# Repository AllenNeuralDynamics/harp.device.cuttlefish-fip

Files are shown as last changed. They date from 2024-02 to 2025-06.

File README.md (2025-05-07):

A [Cuttlefish](https://github.com/AllenNeuralDynamics/harp.device.cuttlefish) adapted to a dedicated fiber photometry application.

## Waveform Parameter Overview
This firmware generates the waveform below.

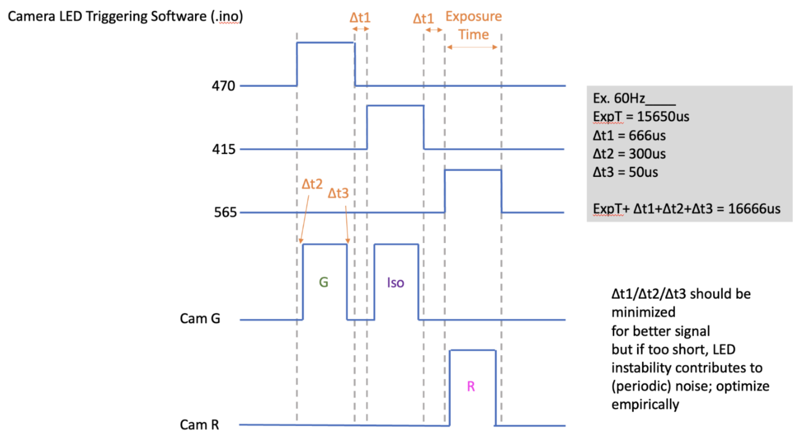
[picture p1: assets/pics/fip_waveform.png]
fip_waveform


Multiple parameters are configurable:
* Continuous, or iterations
* software-trigger to start waveform generation
* `EVENT` message emitted upon rising edge of any camera trigger (configurable)

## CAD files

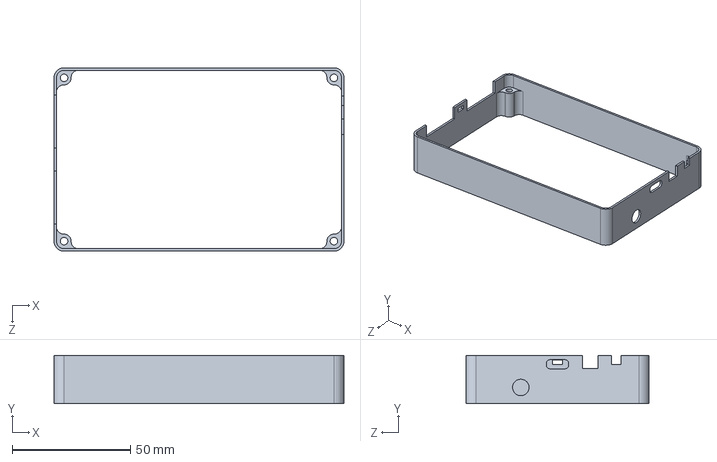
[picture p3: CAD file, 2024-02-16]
hardware/enclosure/cads/solidworks/cuttlefish_enclosure.SLDPRT
122.5 x 20.4 x 77.5 mm

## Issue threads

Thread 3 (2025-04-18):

Device should stop generating waveforms after disconnecting

bruno-f-cruz, 2025-04-18:
If in USB mode, once a client disconnects, would be great to automatically disable all ongoing pulses.

Poofjunior, 2025-04-21:
Ok, this is now implemented in the feat/fip-draft branch.

Upon entering STANDBY (op) mode, the device will disable waveform output, and it's enabled state in the Harp registers will be updated accordingly.

I added a PR to the Harp Core to [make op mode easier to access](https://github.com/harp-tech/core.pico/pull/49).

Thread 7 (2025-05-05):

Allow ongoing tasks to be cancelled immediately

bruno-f-cruz, 2025-05-05:
Currently, the `Stop` command via the reg:

https://github.com/AllenNeuralDynamics/harp.device.cuttlefish-fip/blob/14603b114729877e85d4ecf958180f8078132ae1/device.yml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

awaits for the completion of an ongoing task to take effect. This leads an inability to:

`Stop Task -> Clear Tasks -> Add Task (s) -> Start Tasks` until the first Stop Task is completed. On top of that, since Stop Task does not return an event when it successfully completes, the only thing left to do is to read all tasks, sum all Ts, and await, maximally, that amount of time. This is especially bad if the tasks running have a long duration (e.g., during bleaching or calibration routines).

It would be great if, on top of the current Stop functionality, we could have a value that aborts the currently ongoing sequence instead, regardless of its state.

I propose refactoring the "StartTasks" register into something more like "SetTasksState" that implements an enum:

```
Start 0x01
Stop 0x00
Abort 0x02
(other potential modes in the future like "Pause" and "Resume")
```

Closed 2025-06-28.

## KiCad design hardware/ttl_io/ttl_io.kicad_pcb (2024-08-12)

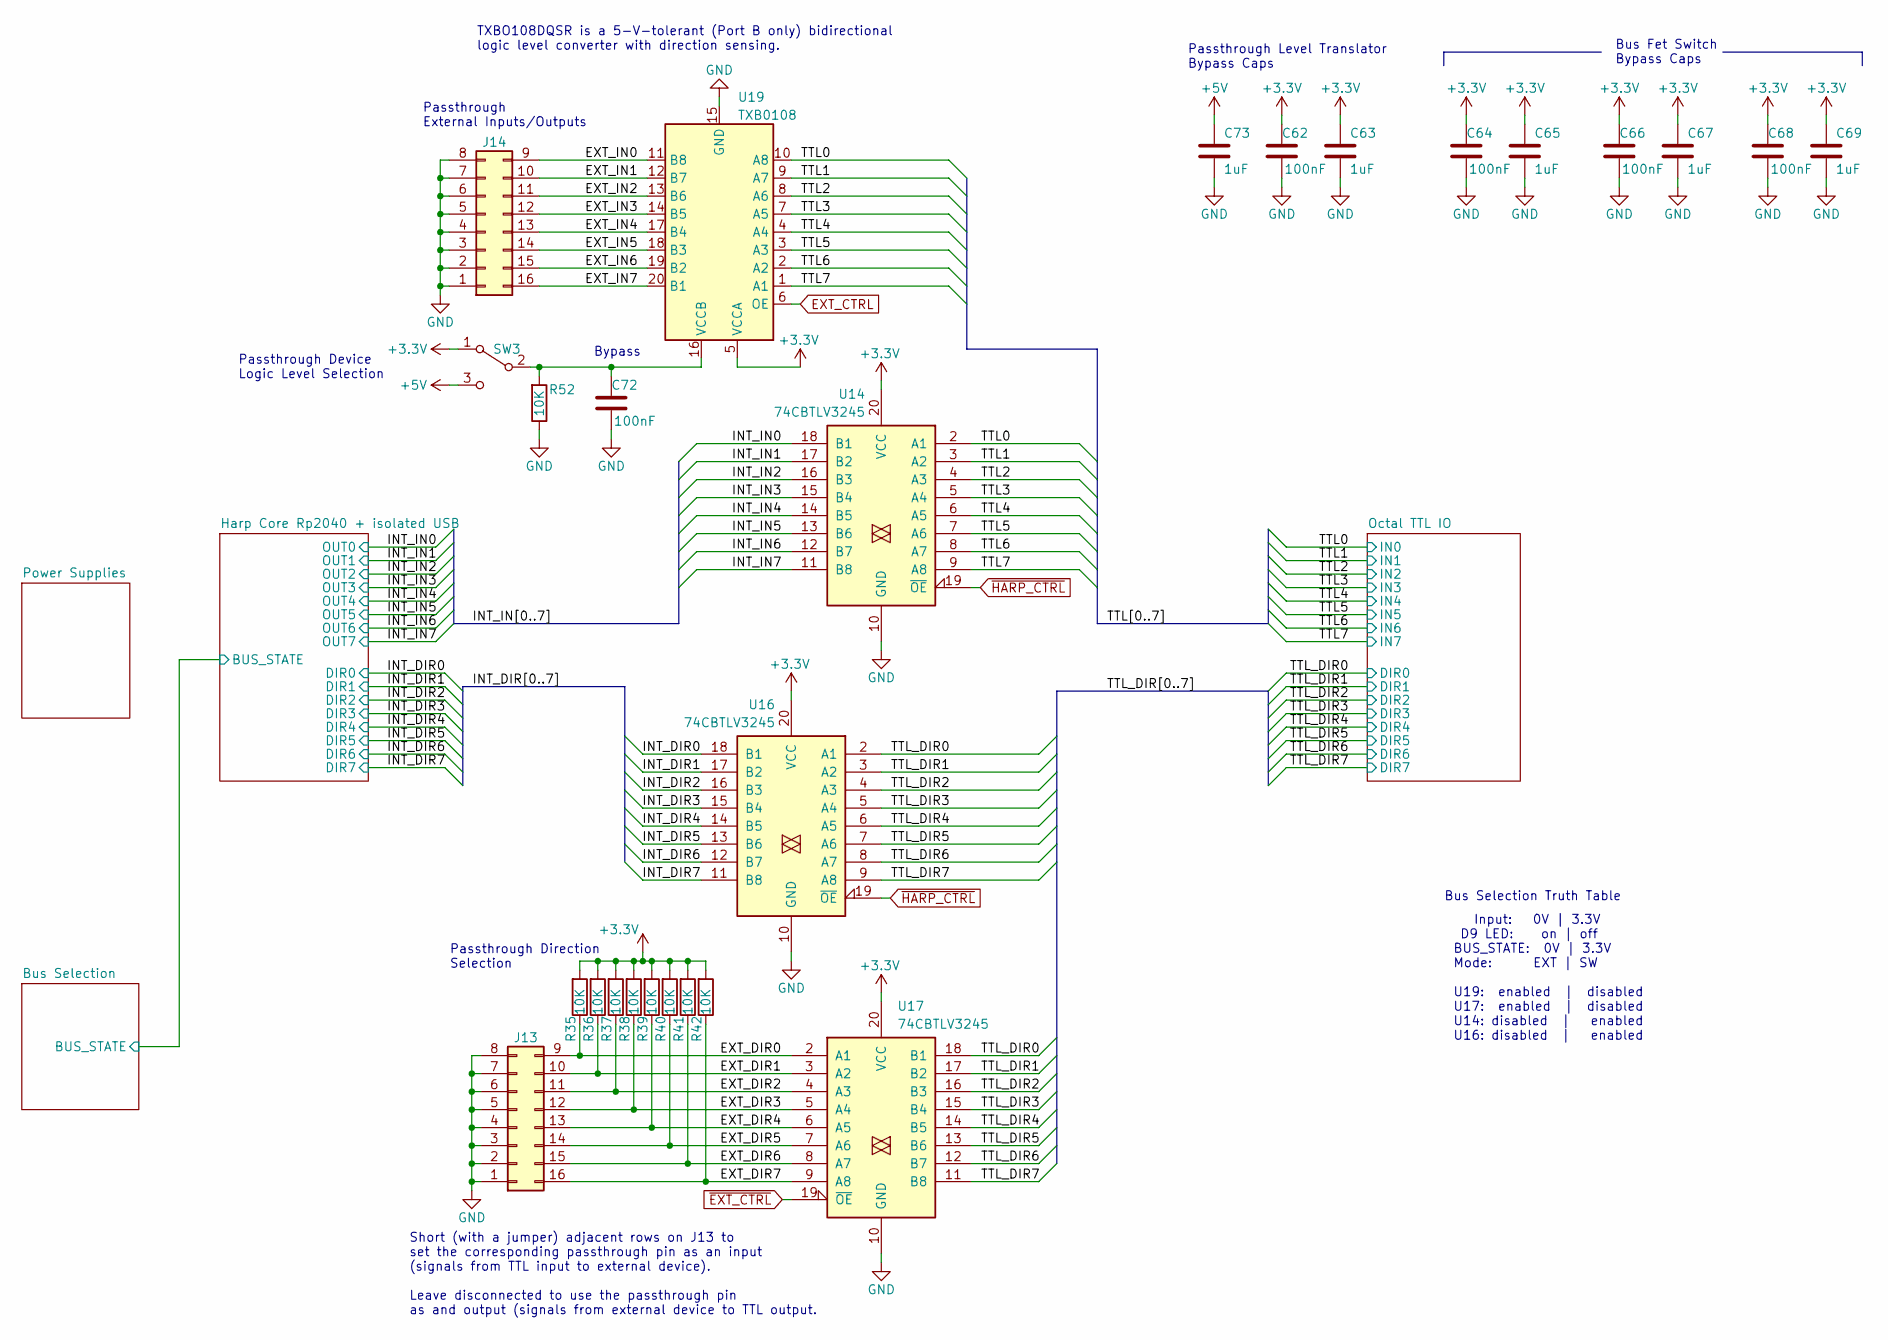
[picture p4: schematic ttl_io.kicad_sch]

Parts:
C62, C64, C66, C68, C72: 100nF; C_0402_1005Metric; Rated Voltage 16V; Tolerance 10%
C63, C65, C67, C69, C73: 1uF; C_0402_1005Metric; Rated Voltage 35V
J13, J14: Conn_02x08_Counter_Clockwise; PinHeader_2x08_P2.54mm_Horizontal_SMD
R35, R36, R37, R38, R39, R40, R41, R42, R52: 10K; R_0402_1005Metric
SW3: SW_SPDT; SW_SPDT_CK-JS102011SAQN
U14, U16, U17: 74CBTLV3245; TSSOP-20_4.4x6.5mm_P0.65mm
U19: TXB0108; TSSOP-20_4.4x6.5mm_P0.65mm

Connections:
+5V: C73.1, SW3.3 (C); also elsewhere on the board
/EXT_DIR0: J13.9, R35.1, U17.2 (A1)
/EXT_DIR1: J13.10, R36.1, U17.3 (A2)
/EXT_DIR2: J13.11, R37.1, U17.4 (A3)
/EXT_DIR3: J13.12, R38.1, U17.5 (A4)
/EXT_DIR4: J13.13, R39.1, U17.6 (A5)
/EXT_DIR5: J13.14, R40.1, U17.7 (A6)
/EXT_DIR6: J13.15, R41.1, U17.8 (A7)
/EXT_DIR7: J13.16, R42.1, U17.9 (A8)
/EXT_IN0: J14.9, U19.11 (B8)
/EXT_IN1: J14.10, U19.12 (B7)
/EXT_IN2: J14.11, U19.13 (B6)
/EXT_IN3: J14.12, U19.14 (B5)
/EXT_IN4: J14.13, U19.17 (B4)
/EXT_IN5: J14.14, U19.18 (B3)
/EXT_IN6: J14.15, U19.19 (B2)
/EXT_IN7: J14.16, U19.20 (B1)
/INT_DIR0: U16.18 (B1); also elsewhere on the board
/INT_DIR1: U16.17 (B2); also elsewhere on the board
/INT_DIR2: U16.16 (B3); also elsewhere on the board
/INT_DIR3: U16.15 (B4); also elsewhere on the board
/INT_DIR4: U16.14 (B5); also elsewhere on the board
/INT_DIR5: U16.13 (B6); also elsewhere on the board
/INT_DIR6: U16.12 (B7); also elsewhere on the board
/INT_DIR7: U16.11 (B8); also elsewhere on the board
/INT_IN0: U14.18 (B1); also elsewhere on the board
/INT_IN1: U14.17 (B2); also elsewhere on the board
/INT_IN2: U14.16 (B3); also elsewhere on the board
/INT_IN3: U14.15 (B4); also elsewhere on the board
/INT_IN4: U14.14 (B5); also elsewhere on the board
/INT_IN5: U14.13 (B6); also elsewhere on the board
/INT_IN6: U14.12 (B7); also elsewhere on the board
/INT_IN7: U14.11 (B8); also elsewhere on the board
/TTL0: U14.2 (A1), U19.10 (A8); also elsewhere on the board
/TTL1: U14.3 (A2), U19.9 (A7); also elsewhere on the board
/TTL2: U14.4 (A3), U19.8 (A6); also elsewhere on the board
/TTL3: U14.5 (A4), U19.7 (A5); also elsewhere on the board
/TTL4: U14.6 (A5), U19.4 (A4); also elsewhere on the board
/TTL5: U14.7 (A6), U19.3 (A3); also elsewhere on the board
/TTL6: U14.8 (A7), U19.2 (A2); also elsewhere on the board
/TTL7: U14.9 (A8), U19.1 (A1); also elsewhere on the board
/TTL_DIR0: U16.2 (A1), U17.18 (B1); also elsewhere on the board
/TTL_DIR1: U16.3 (A2), U17.17 (B2); also elsewhere on the board
/TTL_DIR2: U16.4 (A3), U17.16 (B3); also elsewhere on the board
/TTL_DIR3: U16.5 (A4), U17.15 (B4); also elsewhere on the board
/TTL_DIR4: U16.6 (A5), U17.14 (B5); also elsewhere on the board
/TTL_DIR5: U16.7 (A6), U17.13 (B6); also elsewhere on the board
/TTL_DIR6: U16.8 (A7), U17.12 (B7); also elsewhere on the board
/TTL_DIR7: U16.9 (A8), U17.11 (B8); also elsewhere on the board
EXT_CTRL: U19.6 (OE); also elsewhere on the board
GND: C62.1, C63.2, C64.1, C65.2, C66.1, C67.2, C68.1, C69.2, C72.1, C73.2, J13.1, J13.2, J13.3, J13.4, J13.5, J13.6, J13.7, J13.8, J14.1, J14.2, J14.3, J14.4, J14.5, J14.6, J14.7, J14.8, R52.1, U14.10 (GND), U16.10 (GND), U17.10 (GND), U19.15 (GND); also elsewhere on the board
unnamed: C72.2, R52.2, SW3.2 (B), U19.16 (VCCB)
~EXT_CTRL: U17.19 (~OE); also elsewhere on the board
~HARP_CTRL: U14.19 (~OE), U16.19 (~OE); also elsewhere on the board

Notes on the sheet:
Passthrough External Inputs/Outputs
Input: 0V | 3.3V D9 LED: on | off BUS_STATE: 0V | 3.3V Mode: EXT | SW U19: enabled | disabled U17: enabled | disabled U14: disabled | enabled U16: disabled | enabled
Passthrough Direction Selection
Bus Fet Switch Bypass Caps
TXBO108DQSR is a 5-V-tolerant (Port B only) bidirectional logic level converter with direction sensing.
Short (with a jumper) adjacent rows on J13 to set the corresponding passthrough pin as an input (signals from TTL input to external device). Leave disconnected to use the passthrough pin as and output (signals from external device to TTL output.
Passthrough Device Logic Level Selection
Bypass
Passthrough Level Translator Bypass Caps
Bus Selection Truth Table

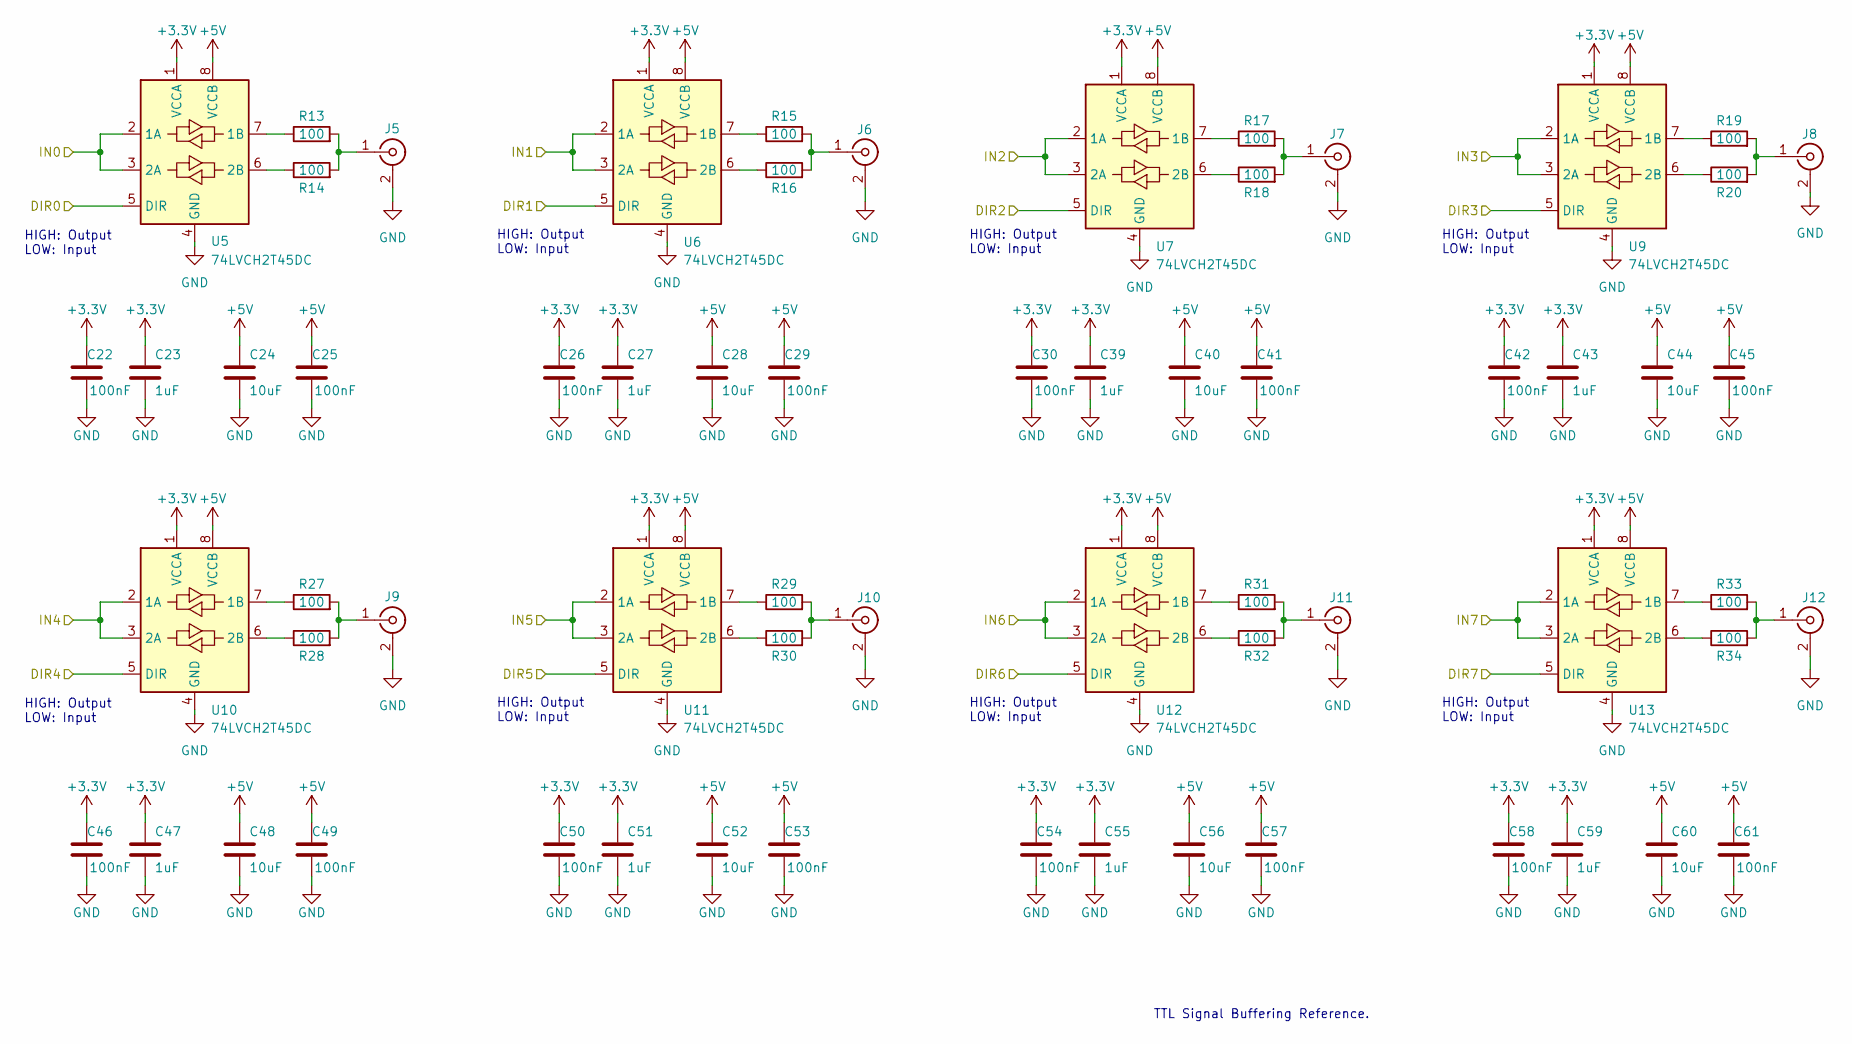
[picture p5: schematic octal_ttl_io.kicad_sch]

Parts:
C22, C25, C26, C29, C30, C41, C42, C45, C46, C49, C50, C53, C54, C57, C58, C61: 100nF; C_0402_1005Metric; Rated Voltage 16V; Tolerance 10%
C23, C27, C39, C43, C47, C51, C55, C59: 1uF; C_0402_1005Metric; Rated Voltage 35V
C24, C28, C40, C44, C48, C52, C56, C60: 10uF; C_0805_2012Metric; Rated Voltage 25V
J5, J6, J7, J8, J9, J10, J11, J12: Conn_Coaxial; BNC_AmphenolRF_031-5329-52RFX_Vertical
R13, R14, R15, R16, R17, R18, R19, R20, R27, R28, R29, R30, R31, R32, R33, R34: 100; R_0402_1005Metric; Tolerance 1%
U5, U6, U7, U9, U10, U11, U12, U13: 74LVCH2T45DC; VSSOP-8_2.3x2mm_P0.5mm

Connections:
+5V: C24.1, C25.2, C28.1, C29.2, C40.1, C41.2, C44.1, C45.2, C48.1, C49.2, C52.1, C53.2, C56.1, C57.2, C60.1, C61.2, U5.8 (VCCB), U6.8 (VCCB), U7.8 (VCCB), U9.8 (VCCB), U10.8 (VCCB), U11.8 (VCCB), U12.8 (VCCB), U13.8 (VCCB); also elsewhere on the board
/TTL0: U5.2 (1A), U5.3 (2A); also elsewhere on the board
/TTL1: U6.2 (1A), U6.3 (2A); also elsewhere on the board
/TTL2: U7.2 (1A), U7.3 (2A); also elsewhere on the board
/TTL3: U9.2 (1A), U9.3 (2A); also elsewhere on the board
/TTL4: U10.2 (1A), U10.3 (2A); also elsewhere on the board
/TTL5: U11.2 (1A), U11.3 (2A); also elsewhere on the board
/TTL6: U12.2 (1A), U12.3 (2A); also elsewhere on the board
/TTL7: U13.2 (1A), U13.3 (2A); also elsewhere on the board
/TTL_DIR0: U5.5 (DIR); also elsewhere on the board
/TTL_DIR1: U6.5 (DIR); also elsewhere on the board
/TTL_DIR2: U7.5 (DIR); also elsewhere on the board
/TTL_DIR3: U9.5 (DIR); also elsewhere on the board
/TTL_DIR4: U10.5 (DIR); also elsewhere on the board
/TTL_DIR5: U11.5 (DIR); also elsewhere on the board
/TTL_DIR6: U12.5 (DIR); also elsewhere on the board
/TTL_DIR7: U13.5 (DIR); also elsewhere on the board
GND: C22.1, C23.2, C24.2, C25.1, C26.1, C27.2, C28.2, C29.1, C30.1, C39.2, C40.2, C41.1, C42.1, C43.2, C44.2, C45.1, C46.1, C47.2, C48.2, C49.1, C50.1, C51.2, C52.2, C53.1, C54.1, C55.2, C56.2, C57.1, C58.1, C59.2, C60.2, C61.1, J5.2 (Ext), J6.2 (Ext), J7.2 (Ext), J8.2 (Ext), J9.2 (Ext), J10.2 (Ext), J11.2 (Ext), J12.2 (Ext), U5.4 (GND), U6.4 (GND), U7.4 (GND), U9.4 (GND), U10.4 (GND), U11.4 (GND), U12.4 (GND), U13.4 (GND); also elsewhere on the board
unnamed: J5.1 (In), R13.2, R14.2
unnamed: J6.1 (In), R15.2, R16.2
unnamed: J7.1 (In), R17.2, R18.2
unnamed: J8.1 (In), R19.2, R20.2
unnamed: J9.1 (In), R27.2, R28.2
unnamed: J10.1 (In), R29.2, R30.2
unnamed: J11.1 (In), R31.2, R32.2
unnamed: J12.1 (In), R33.2, R34.2
unnamed: R13.1, U5.7 (1B)
unnamed: R14.1, U5.6 (2B)
unnamed: R15.1, U6.7 (1B)
unnamed: R16.1, U6.6 (2B)
unnamed: R17.1, U7.7 (1B)
unnamed: R18.1, U7.6 (2B)
unnamed: R19.1, U9.7 (1B)
unnamed: R20.1, U9.6 (2B)
unnamed: R27.1, U10.7 (1B)
unnamed: R28.1, U10.6 (2B)
unnamed: R29.1, U11.7 (1B)
unnamed: R30.1, U11.6 (2B)
unnamed: R31.1, U12.7 (1B)
unnamed: R32.1, U12.6 (2B)
unnamed: R33.1, U13.7 (1B)
unnamed: R34.1, U13.6 (2B)

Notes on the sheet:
HIGH: Output LOW: Input
TTL Signal Buffering Reference.

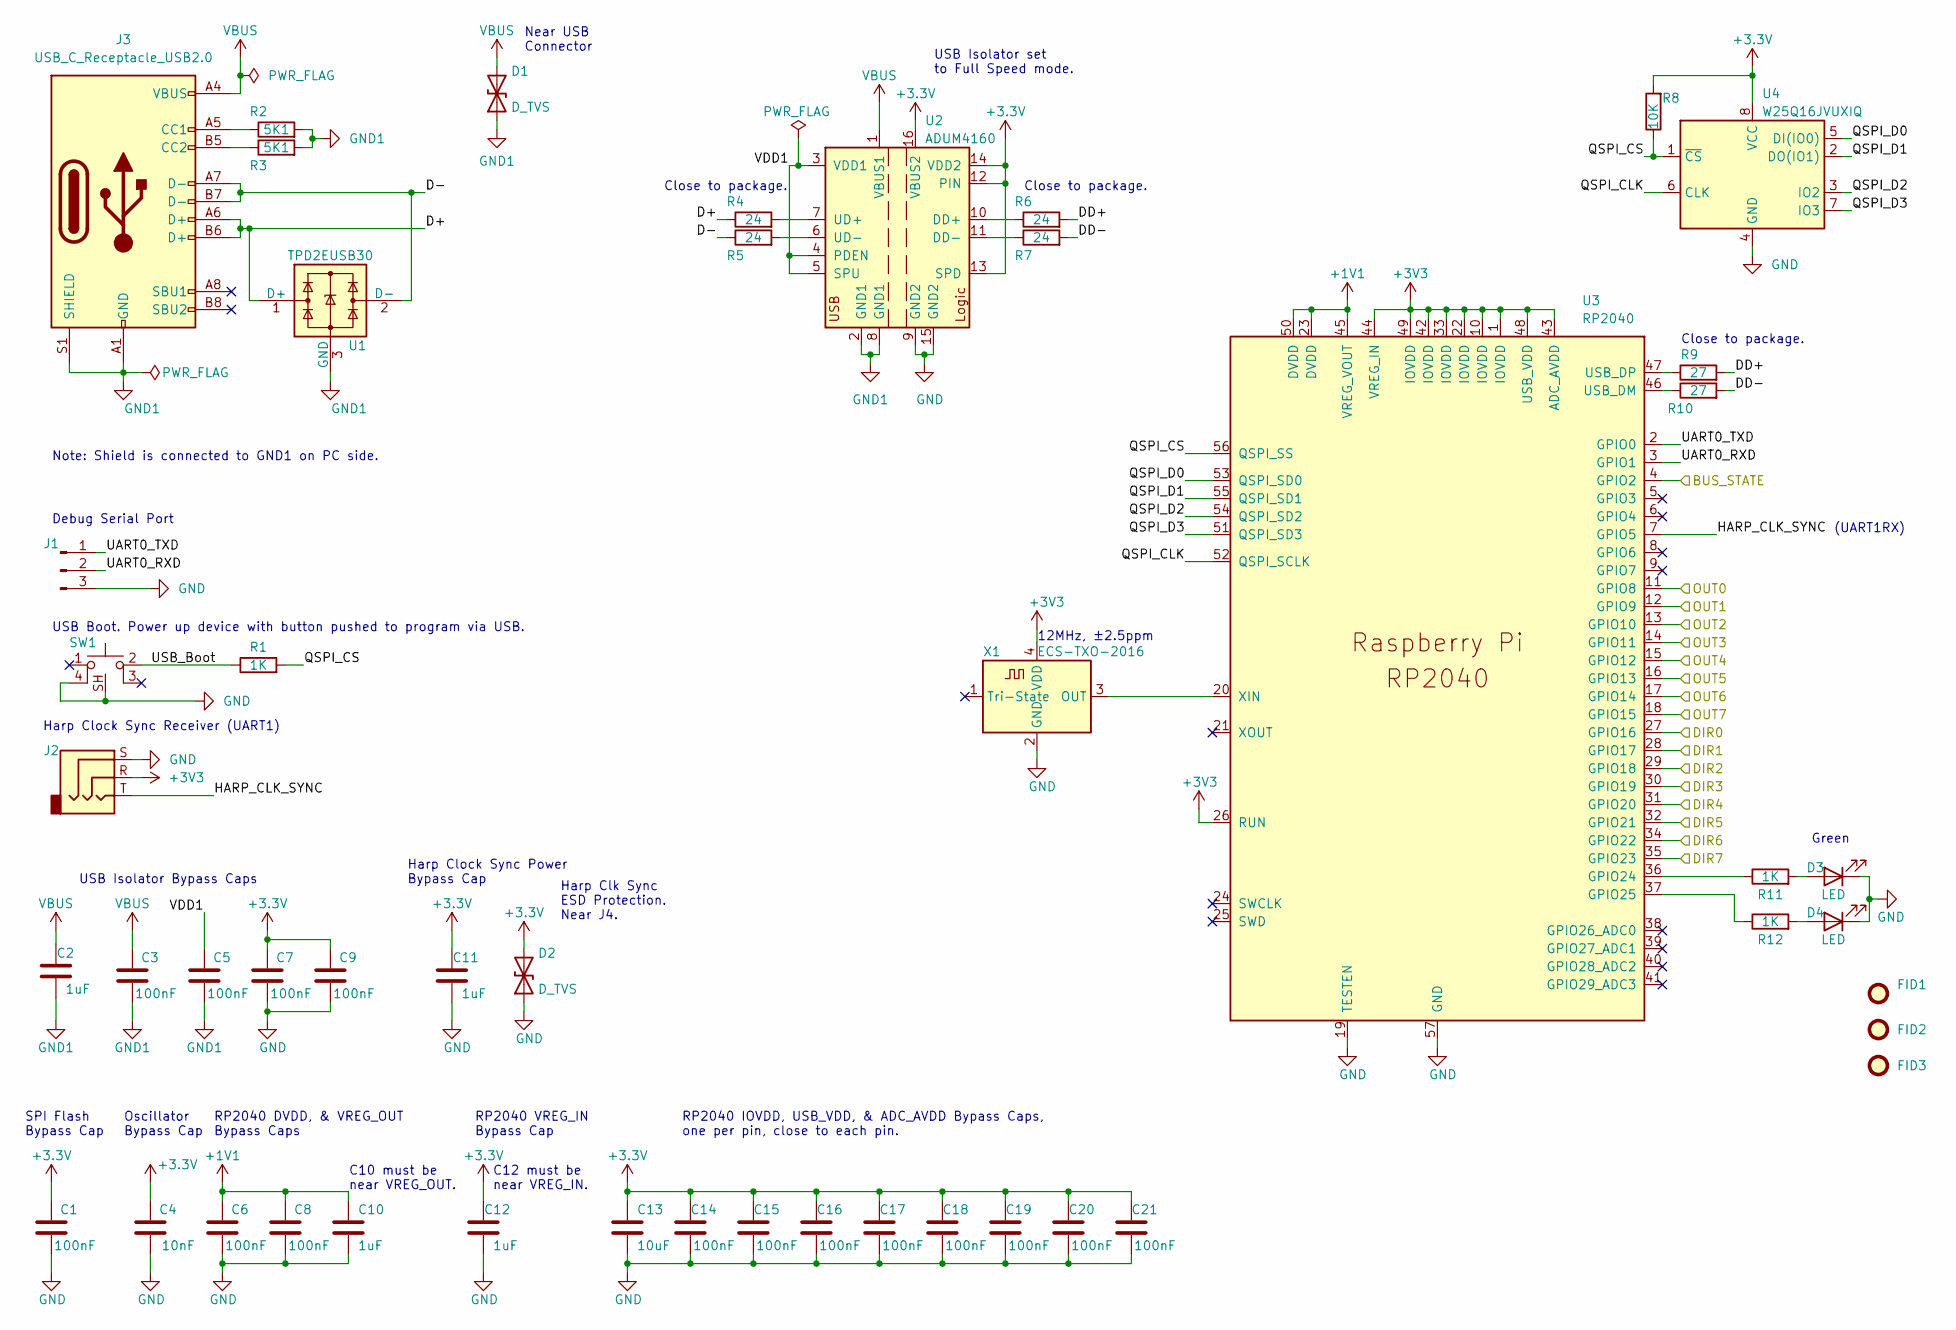
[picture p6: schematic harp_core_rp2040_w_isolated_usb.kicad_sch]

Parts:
C1, C3, C5, C6, C7, C8, C9, C14, C15, C16, C17, C18, C19, C20, C21: 100nF; C_0402_1005Metric; Rated Voltage 16V; Tolerance 10%
C2, C10, C11, C12: 1uF; C_0402_1005Metric; Rated Voltage 35V
C4: 10nF; C_0402_1005Metric; Rated Voltage 25V; Tolerance 10%
C13: 10uF; C_0805_2012Metric; Rated Voltage 25V
D1, D2: D_TVS; D_0402_1005Metric
D3, D4: LED; LED_0603_1608Metric
FID1, FID2, FID3: Fiducial; Fiducial_0.5mm_Mask1mm
J1: Conn_01x03_Male; PinHeader_1x03_P2.54mm_Vertical
J2: AudioJack3; Jack_3.5mm_CUI_SJ-3523-SMT_Horizontal
J3: USB_C_Receptacle_USB2.0; USB_C_Receptacle_JAE_DX07S016JA1R1500
R1, R11, R12: 1K; R_0402_1005Metric; Tolerance 1%
R2, R3: 5K1; R_0402_1005Metric; Tolerance 1%
R4, R5, R6, R7: 24; R_0402_1005Metric; Tolerance 1%
R8: 10K; R_0402_1005Metric
R9, R10: 27; R_0402_1005Metric; Tolerance 1%
SW1: SW_Push_1P1T-SH_NO_Vertical_Wuerth_WS-TASV
U1: TPD2EUSB30; Texas_DRT-3
U2: ADUM4160; SOIC-16W_7.5x10.3mm_P1.27mm
U3: RP2040; RP2040-QFN-56
U4: W25Q16JVUXIQ; Winbond-8USON-2x3mm
X1: ECS-TXO-2016; Crystal_SMD_2016-4Pin_2.0x1.6mm; Tolerance ±2.5ppm

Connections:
+1V1: C6.2, C8.2, C10.1, U3.23 (DVDD), U3.45 (VREG_VOUT), U3.50 (DVDD)
/Bus Selection/BUS_STATE: U3.4 (GPIO2); also elsewhere on the board
/Harp Core Rp2040 + isolated USB/D+: J3.A6 (D+), J3.B6 (D+), R4.1, U1.1 (D+)
/Harp Core Rp2040 + isolated USB/D-: J3.A7 (D-), J3.B7 (D-), R5.1, U1.2 (D-)
/Harp Core Rp2040 + isolated USB/DD+: R6.2, R9.2
/Harp Core Rp2040 + isolated USB/DD-: R7.2, R10.2
/Harp Core Rp2040 + isolated USB/HARP_CLK_SYNC: J2.T, U3.7 (GPIO5)
/Harp Core Rp2040 + isolated USB/QSPI_CLK: U3.52 (QSPI_SCLK), U4.6 (CLK)
/Harp Core Rp2040 + isolated USB/QSPI_CS: R1.2, R8.1, U3.56 (QSPI_SS), U4.1 (~CS)
/Harp Core Rp2040 + isolated USB/QSPI_D0: U3.53 (QSPI_SD0), U4.5 (DI(IO0))
/Harp Core Rp2040 + isolated USB/QSPI_D1: U3.55 (QSPI_SD1), U4.2 (DO(IO1))
/Harp Core Rp2040 + isolated USB/QSPI_D2: U3.54 (QSPI_SD2), U4.3 (IO2)
/Harp Core Rp2040 + isolated USB/QSPI_D3: U3.51 (QSPI_SD3), U4.7 (IO3)
/Harp Core Rp2040 + isolated USB/UART0_RXD: J1.2, U3.3 (GPIO1)
/Harp Core Rp2040 + isolated USB/UART0_TXD: J1.1, U3.2 (GPIO0)
/Harp Core Rp2040 + isolated USB/USB_Boot: R1.1, SW1.2
/Harp Core Rp2040 + isolated USB/VDD1: C5.2, U2.3 (VDD1), U2.4 (PDEN), U2.5 (SPU)
/INT_DIR0: U3.27 (GPIO16); also elsewhere on the board
/INT_DIR1: U3.28 (GPIO17); also elsewhere on the board
/INT_DIR2: U3.29 (GPIO18); also elsewhere on the board
/INT_DIR3: U3.30 (GPIO19); also elsewhere on the board
/INT_DIR4: U3.31 (GPIO20); also elsewhere on the board
/INT_DIR5: U3.32 (GPIO21); also elsewhere on the board
/INT_DIR6: U3.34 (GPIO22); also elsewhere on the board
/INT_DIR7: U3.35 (GPIO23); also elsewhere on the board
/INT_IN0: U3.11 (GPIO8); also elsewhere on the board
/INT_IN1: U3.12 (GPIO9); also elsewhere on the board
/INT_IN2: U3.13 (GPIO10); also elsewhere on the board
/INT_IN3: U3.14 (GPIO11); also elsewhere on the board
/INT_IN4: U3.15 (GPIO12); also elsewhere on the board
/INT_IN5: U3.16 (GPIO13); also elsewhere on the board
/INT_IN6: U3.17 (GPIO14); also elsewhere on the board
/INT_IN7: U3.18 (GPIO15); also elsewhere on the board
GND: C1.1, C4.1, C6.1, C7.1, C8.1, C9.1, C10.2, C11.2, C12.2, C13.2, C14.1, C15.1, C16.1, C17.1, C18.1, C19.1, C20.1, C21.1, D2.1 (A1), D3.1 (K), D4.1 (K), J1.3, J2.S, SW1.4, SW1.SH, U2.9 (GND2), U2.15 (GND2), U3.19 (TESTEN), U3.57 (GND), U4.4 (GND), X1.2 (GND); also elsewhere on the board
GND1: C2.2, C3.1, C5.1, D1.1 (A1), J3.A1 (GND), J3.A12 (GND), J3.B1 (GND), J3.B12 (GND), J3.S1 (SHIELD), R2.2, R3.2, U1.3 (GND), U2.2 (GND1), U2.8 (GND1)
unnamed: D3.2 (A), R11.2
unnamed: D4.2 (A), R12.2
unnamed: J3.A5 (CC1), R2.1
unnamed: J3.B5 (CC2), R3.1
unnamed: R6.1, U2.10 (DD+)
unnamed: R7.1, U2.11 (DD-)
unnamed: R4.2, U2.7 (UD+)
unnamed: R5.2, U2.6 (UD-)
unnamed: R11.1, U3.36 (GPIO24)
unnamed: R12.1, U3.37 (GPIO25)
unnamed: R10.1, U3.46 (USB_DM)
unnamed: R9.1, U3.47 (USB_DP)
unnamed: U3.20 (XIN), X1.3 (OUT)
VBUS: C2.1, C3.2, D1.2 (A2), J3.A4 (VBUS), J3.A9 (VBUS), J3.B4 (VBUS), J3.B9 (VBUS), U2.1 (VBUS1)

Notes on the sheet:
USB Isolator Bypass Caps
Near USB Connector
Close to package.
Harp Clock Sync Power Bypass Cap
USB Isolator set to Full Speed mode.
12MHz, ±2.5ppm
Debug Serial Port
USB Boot. Power up device with button pushed to program via USB.
(UART1RX)
Harp Clock Sync Receiver (UART1)
Note: Shield is connected to GND1 on PC side.
RP2040 DVDD, & VREG_OUT Bypass Caps
RP2040 IOVDD, USB_VDD, & ADC_AVDD Bypass Caps, one per pin, close to each pin.
C10 must be near VREG_OUT.
RP2040 VREG_IN Bypass Cap
SPI Flash Bypass Cap
Harp Clk Sync ESD Protection. Near J4.
Oscillator Bypass Cap
C12 must be near VREG_IN.
Green

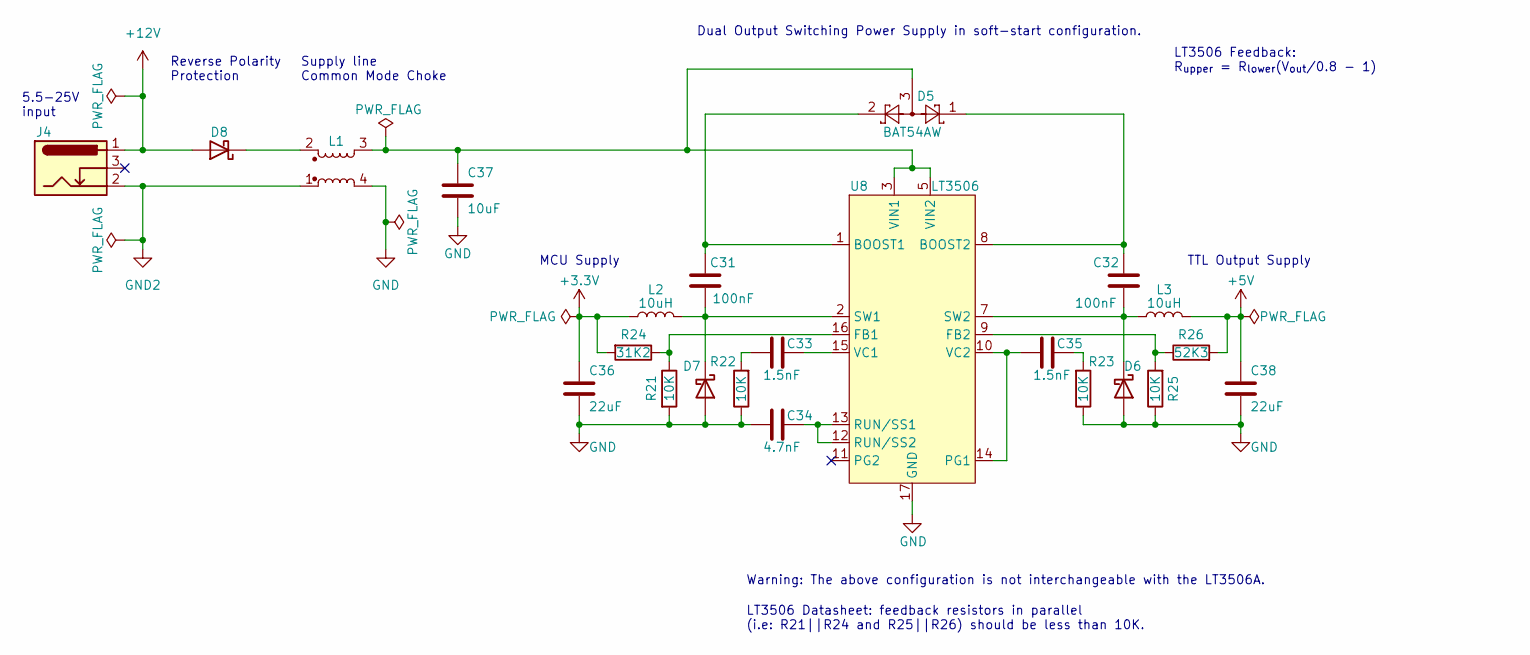
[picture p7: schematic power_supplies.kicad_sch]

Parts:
C31, C32: 100nF; C_0402_1005Metric; Rated Voltage 16V; Tolerance 10%
C33: 1.5nF; R_0402_1005Metric; Tolerance 10%; Voltage Rating 50V
C34: 4.7nF; R_0402_1005Metric; Tolerance 10%; Voltage Rating 50V
C35: 1.5nF; R_0402_1005Metric; Tolerance 10%
C36, C38: 22uF; C_0805_2012Metric; Rated Voltage 25V
C37: 10uF; C_0805_2012Metric; Rated Voltage 25V
D5: BAT54AW; SOT-323_SC-70
D6, D7, D8: D_Schottky; D_SOD-123
J4: Barrel_Jack_Switch; BarrelJack_CUI_PJ-102AH_Horizontal
L1: L_Coupled_1423; L_CommonModeChoke_TDKCorporation_1210
L2, L3: 10uH; L_Vishay_IHLP-2525
R21, R22, R23, R25: 10K; R_0402_1005Metric
R24: 31K2; R_0402_1005Metric; Tolerance 1%
R26: 52K3; R_0402_1005Metric; Tolerance 1%
U8: LT3506; DFN-16-1EP_4x5mm_P0.5mm_EP2.44x4.34mm

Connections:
+5V: C38.1, L3.2, R26.2; also elsewhere on the board
+12V: D8.2 (A), J4.1
GND: C34.1, C36.2, C37.2, C38.2, D6.2 (A), D7.2 (A), L1.4, R21.2, R22.1, R23.1, R25.1, U8.17 (GND); also elsewhere on the board
GND2: J4.2, L1.1
unnamed: C33.1, R22.2
unnamed: C35.2, R23.2
unnamed: C32.1, D6.1 (K), L3.1, U8.7 (SW2)
unnamed: C31.1, D7.1 (K), L2.2, U8.2 (SW1)
unnamed: D8.1 (K), L1.2
unnamed: C31.2, D5.2, U8.1 (BOOST1)
unnamed: C32.2, D5.1, U8.8 (BOOST2)
unnamed: R21.1, R24.1, U8.16 (FB1)
unnamed: R25.2, R26.1, U8.9 (FB2)
unnamed: C35.1, U8.10 (VC2), U8.14 (PG1)
unnamed: C34.2, U8.12 (RUN/SS2), U8.13 (RUN/SS1)
unnamed: C33.2, U8.15 (VC1)
VIN1: C37.1, D5.3, L1.3, U8.3 (VIN1), U8.4 (VIN1), U8.5 (VIN2), U8.6 (VIN2)

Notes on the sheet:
Reverse Polarity Protection
LT3506 Datasheet: feedback resistors in parallel (i.e: R21||R24 and R25||R26) should be less than 10K.
TTL Output Supply
Supply line Common Mode Choke
Dual Output Switching Power Supply in soft-start configuration.
LT3506 Feedback: R_{upper} = R_{lower}(V_{out}/0.8 - 1)
Warning: The above configuration is not interchangeable with the LT3506A.
MCU Supply
5.5-25V input

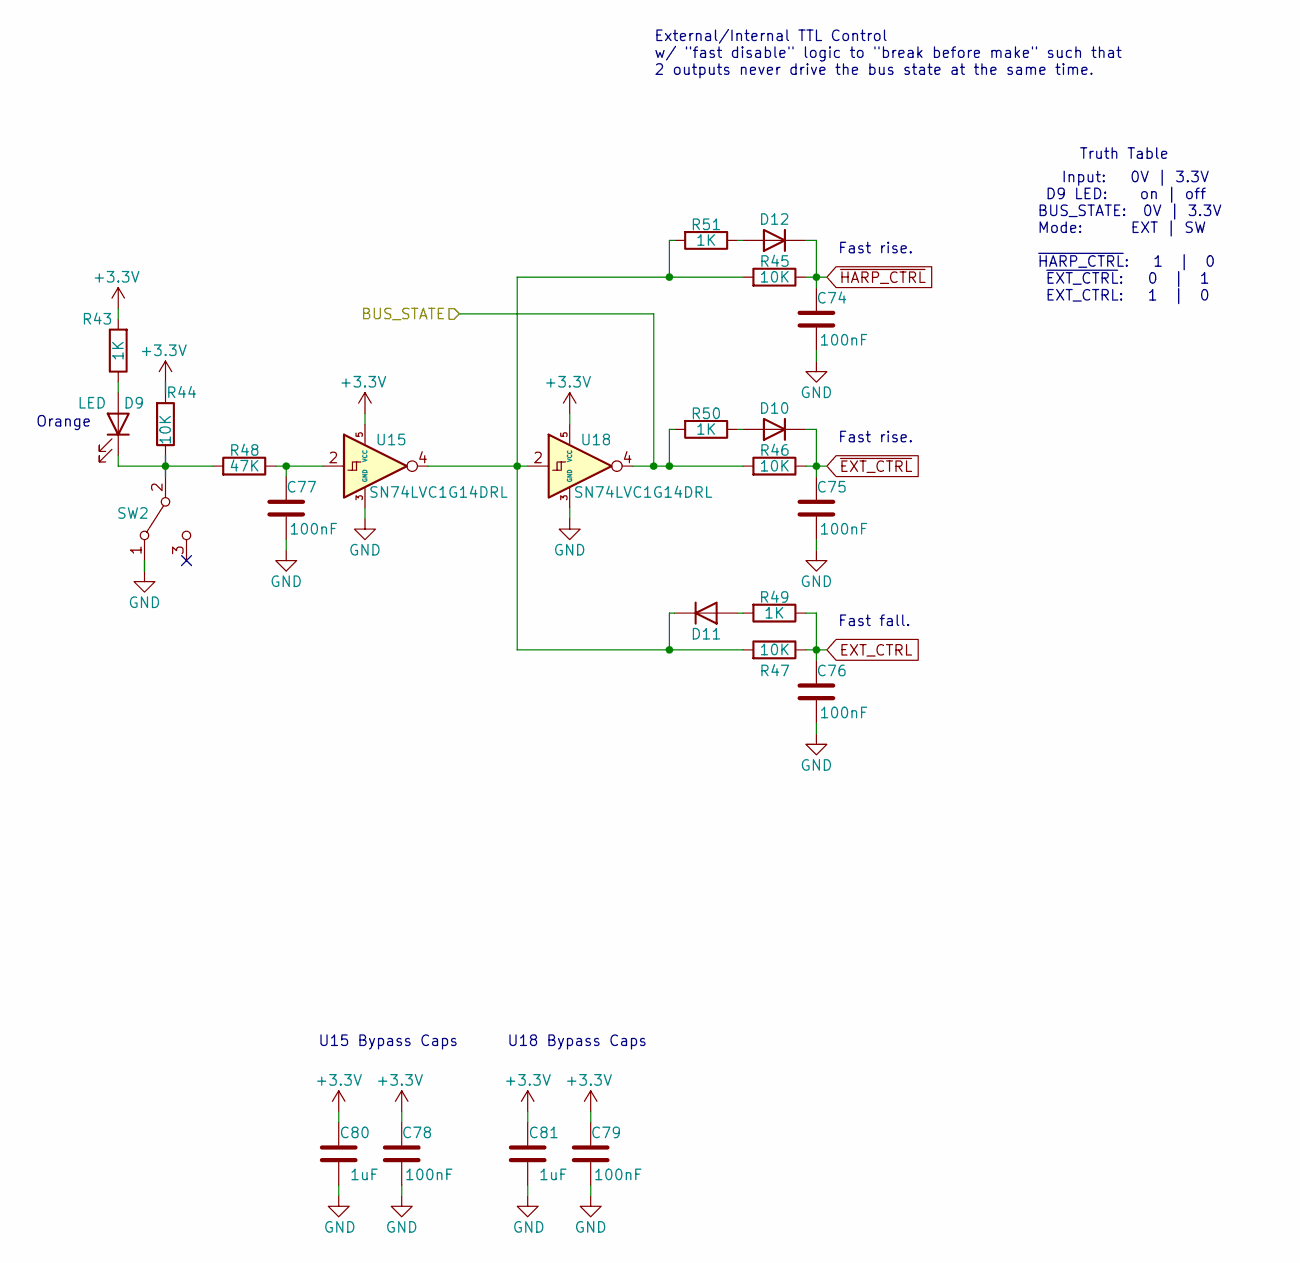
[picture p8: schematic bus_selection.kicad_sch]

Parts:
C74, C75, C76, C77, C78, C79: 100nF; C_0402_1005Metric; Rated Voltage 16V; Tolerance 10%
C80, C81: 1uF; C_0402_1005Metric; Rated Voltage 35V
D9: LED; LED_0603_1608Metric
D10, D11, D12: NSR05F40NXT5G; D_0402_1005Metric
R43, R49, R50, R51: 1K; R_0402_1005Metric; Tolerance 1%
R44, R45, R46, R47: 10K; R_0402_1005Metric
R48: 47K; R_0402_1005Metric; Tolerance 1%
SW2: SW_SPDT; SW_SPDT_CK-JS102011SAQN
U15, U18: SN74LVC1G14DRL; SOT-553

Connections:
/Bus Selection/BUS_STATE: R46.2, R50.2, U18.4; also elsewhere on the board
EXT_CTRL: C76.2, R47.1, R49.1; also elsewhere on the board
GND: C74.1, C75.1, C76.1, C77.1, C78.1, C79.1, C80.2, C81.2, SW2.1 (A), U15.3 (GND), U18.3 (GND); also elsewhere on the board
unnamed: C77.2, R48.1, U15.2
unnamed: D9.2 (A), R43.1
unnamed: D9.1 (K), R44.1, R48.2, SW2.2 (B)
unnamed: D10.2 (A), R50.1
unnamed: D11.2 (A), R49.2
unnamed: D11.1 (K), R45.2, R47.2, R51.2, U15.4, U18.2
unnamed: D12.2 (A), R51.1
~EXT_CTRL: C75.2, D10.1 (K), R46.1; also elsewhere on the board
~HARP_CTRL: C74.2, D12.1 (K), R45.1; also elsewhere on the board

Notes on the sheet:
Truth Table
External/Internal TTL Control w/ "fast disable" logic to "break before make" such that 2 outputs never drive the bus state at the same time.
U18 Bypass Caps
Input: 0V | 3.3V D9 LED: on | off BUS_STATE: 0V | 3.3V Mode: EXT | SW ~{HARP_CTRL}: 1 | 0 ~{EXT_CTRL}: 0 | 1 EXT_CTRL: 1 | 0
U15 Bypass Caps
Fast fall.
Fast rise.
Orange

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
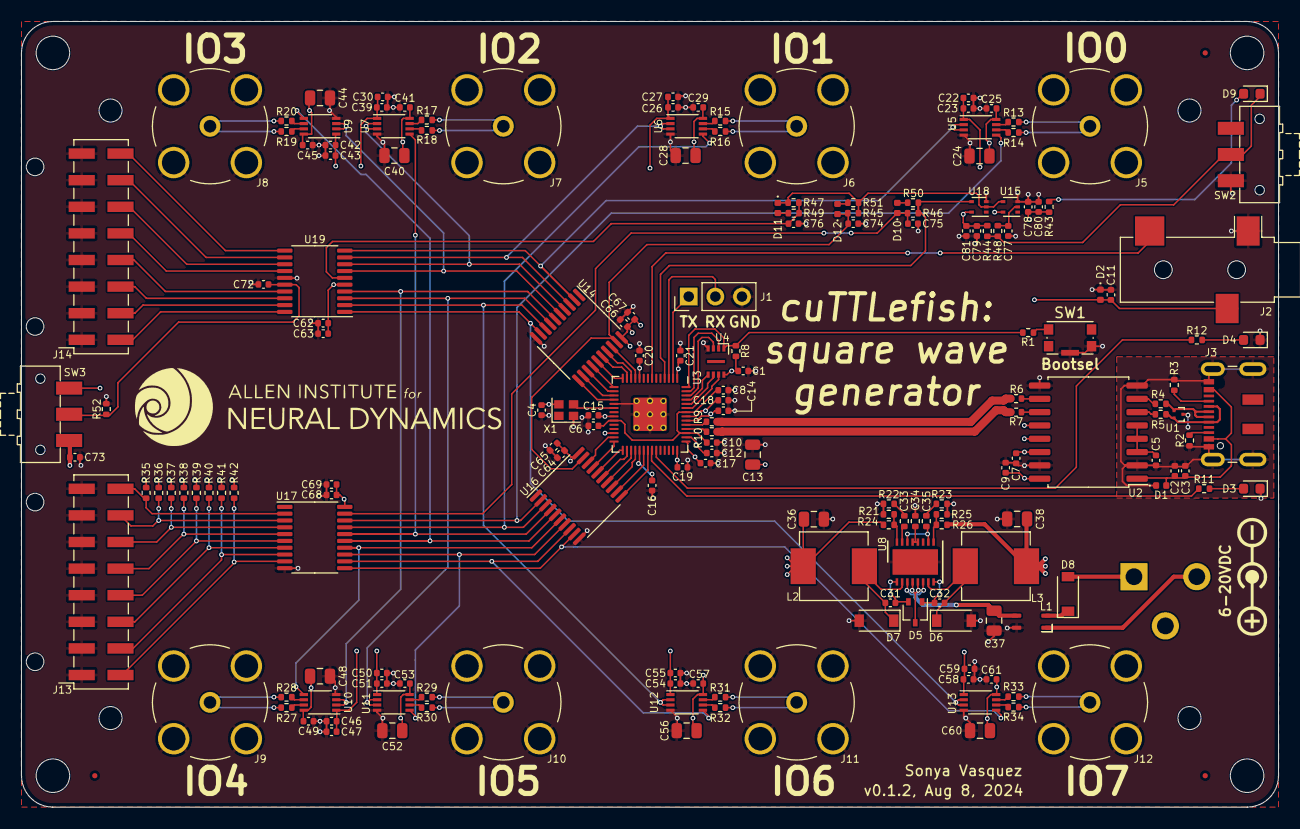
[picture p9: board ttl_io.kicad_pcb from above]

Board: 4 copper layers, 120.0 x 75.0 mm, 188 parts (1 on the bottom side), 133 nets.

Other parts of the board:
G2, G3: LOGO

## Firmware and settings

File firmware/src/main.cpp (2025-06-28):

#include <pico/stdlib.h>
#include <cstring>
#include <config.h>
#include <harp_c_app.h>
#include <harp_synchronizer.h>
#include <cuttlefish_fip_app.h>
#include <fip_ctrl_queues.h>
#include <pico/multicore.h>
#include <hardware/structs/bus_ctrl.h>
#include <core1_main.h>

queue_t set_tasks_state_queue;
queue_t add_task_queue;
queue_t remove_task_queue;
queue_t clear_tasks_queue;
queue_t reconfigure_task_queue;
queue_t rising_edge_event_queue;

HarpCApp& app = HarpCApp::init(FIP_WHO_AM_I, 0, 0,
                               0,
                               0, 0,
                               0, 0,
                               0, "cuttlefish-fip",
                               (uint8_t*)GIT_HASH,
                               &app_regs, app_reg_specs,
                               reg_handler_fns, REG_COUNT, update_app,
                               reset_app);
/*

HarpCApp& app = HarpCApp::init(WHO_AM_I, HW_VERSION_MAJOR, HW_VERSION_MINOR,
                               ASSEMBLY_VERSION,
                               HARP_VERSION_MAJOR, HARP_VERSION_MINOR,
                               FW_VERSION_MAJOR, FW_VERSION_MINOR,
                               SERIAL_NUMBER, "cuttlefish-fip",
                               (uint8_t*)GIT_HASH,
                               &app_regs, app_reg_specs,
                               reg_handler_fns, REG_COUNT, update_app,
                               reset_app);
*/

// Core0 main.
int main()
{
    // Init Synchronizer.
    HarpSynchronizer::init(SYNC_UART, HARP_SYNC_RX_PIN);
    app.set_synchronizer(&HarpSynchronizer::instance());
    // Configure core1 to have high bus priority.
    bus_ctrl_hw->priority = 0x00000010;
    // Initialize queues for multicore communication.
    queue_init(&set_tasks_state_queue, sizeof(uint8_t), MAX_QUEUE_SIZE);
    queue_init(&add_task_queue, sizeof(LaserFIPTaskSettings), MAX_QUEUE_SIZE);
    queue_init(&remove_task_queue, sizeof(uint8_t), MAX_QUEUE_SIZE);
    queue_init(&clear_tasks_queue, sizeof(uint8_t), MAX_QUEUE_SIZE);
    queue_init(&reconfigure_task_queue, sizeof(ReconfigureTaskData), MAX_QUEUE_SIZE);
    queue_init(&rising_edge_event_queue, sizeof(RisingEdgeEventData), MAX_QUEUE_SIZE);

#if defined(DEBUG)
#warning "Initializing printf from UART will slow down core1 main loop."
    stdio_uart_init_full(DEBUG_UART, 921600, DEBUG_UART_TX_PIN, -1);
#endif

    // Launch core1 to juggle pwm tasks.
    multicore_reset_core1();
    (void)multicore_fifo_pop_blocking(); // Wait until core1 is ready.
    multicore_launch_core1(core1_main);

    reset_app();
    while(true)
        app.run();
}

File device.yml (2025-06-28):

%YAML 1.1
---
# yaml-language-server: $schema=https://harp-tech.org/draft-02/schema/device.json
device: CuttlefishFip
whoAmI: 1407
firmwareVersion: "0.1"
hardwareTargets: "0.0"
registers:
  SetTaskState:
    address: 32
    type: U8
    access: Write
    maskType: TaskState
    description: "Controls the state of tasks in the device."
  AddTask:
    address: 33
    type: U8
    access: Write
    length: 34
    description: "Schedules a task by modelling following structure: U32 IOPin, float DutyCycle(0-1), float Frequency(Hz), U32 OutputMask (IOPins), U8 Events (0/1), U8 Mute (Kill the output but preserves timing), u32 delta1-4 (us)"
  RemoveTask:
    address: 34
    type: U8
    access: Write
    maskType: TaskIndex
    description: "Removes a task scheduled at index 0-7. If the task is not scheduled, an error will be returned"
  ClearAllTasks:
    address: 35
    type: U8
    access: Write
    maskType: EnableFlag
    description: "Clears all scheduled task if a value of 1 is written."
  TaskCount:
    address: 36
    type: U8
    access: Read
    description: "Returns the number of tasks currently scheduled. This register is read-only."
  TaskRisingEdgeEvent:
    address: 37
    type: U8
    access: Event
    maskType: Ports
    description: "An event raised when a rising edge of any of the ports is detected. The `Events` flag must be enabled in the corresponding task to trigger this event. The event is raised when the task is started. The event is cleared when the task is removed or stopped."
  Task0Settings: &taskSettings
    address: 38
    type: U8
    length: 34
    access: Write
    description: "Represents the settings of Task0."
  Task1Settings:
    <<: *taskSettings
    address: 39
    description: "Represents the settings of Task1."
  Task2Settings:
    <<: *taskSettings
    address: 40
    description: "Represents the settings of Task2."
  Task3Settings:
    <<: *taskSettings
    address: 41
    description: "Represents the settings of Task3."
  Task4Settings:
    <<: *taskSettings
    address: 42
    description: "Represents the settings of Task4."
  Task5Settings:
    <<: *taskSettings
    address: 43
    description: "Represents the settings of Task5."
  Task6Settings:
    <<: *taskSettings
    address: 44
    description: "Represents the settings of Task6."
  Task7Settings:
    <<: *taskSettings
    address: 45
    description: "Represents the settings of Task7."
groupMasks:
  TaskState:
    description: "The state of the ongoing task."
    values:
      Stop: 0x0
      Start: 0x1
      Abort: 0x2
  TaskIndex:
    description: "Task slot to be used for the task. 0-7"
    values:
      Task0: 0x0
      Task1: 0x1
      Task2: 0x2
      Task3: 0x3
      Task4: 0x4
      Task5: 0x5
      Task6: 0x6
      Task7: 0x7
  Port:
    description: "Available ports on the device. This enum is one-hot encoded. Only one value can be set at a time."
    values:
      None: 0x0
      IO0: 0x1
      IO1: 0x2
      IO2: 0x4
      IO3: 0x8
      IO4: 0x10
      IO5: 0x20
      IO6: 0x40
      IO7: 0x80
bitMasks:
  Ports:
    description: "Available ports on the device. This enum is a bit-mask. Multiple values can be set at the same time."
    bits:
      None: 0x0
      IO0: 0x1
      IO1: 0x2
      IO2: 0x4
      IO3: 0x8
      IO4: 0x10
      IO5: 0x20
      IO6: 0x40
      IO7: 0x80

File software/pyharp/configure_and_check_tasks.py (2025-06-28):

#!/usr/bin/env python3
from pyharp.device import Device
from pyharp.messages import WriteU8HarpMessage, WriteU8ArrayMessage, ReadU8HarpMessage
from pyharp.messages import MessageType
from pyharp.messages import CommonRegisters as Regs
from app_registers import AppRegs
from time import sleep
import serial.tools.list_ports
import sys


# Function to find and connect to the device
def find_device():
    ports = serial.tools.list_ports.comports()
    for port, desc, hwid in sorted(ports):
        if port.startswith("/dev/ttyUSB0") or port.startswith("/dev/ttyACM0") or port.startswith("COM5"):  
            return Device(port)
        elif desc.startswith("cuttlefish-fip"):
            return Device(port)
    raise Exception("Device not found.")


# Function to send FIP waveform settings
def configure_tasks(device):
    settings = [
        (
            0b00000001,   # pwm_pin
            0.25, # pwm duty cycle
            10000., # pwm frequency (hz)
            0b00000010, # output mask
            1,      # events
            0,      # mute
            15350,  # DELTA1
            666,    # DELTA2
            600,    # DELTA3
            50     # DELTA4
        ),

        (
            0b00000100,   # pwm_pin
            0.75, # pwm duty cycle
            10000., # pwm frequency (hz)
            0b00001000, # output mask
            1,      # events
            0,      # mute
            15350,  # DELTA1
            666,    # DELTA2
            600,    # DELTA3
            50     # DELTA4
        ),

        (
            0b00010000,   # pwm_pin
            0.5, # pwm duty cycle
            10000., # pwm frequency (hz)
            0b00100000, # output mask
            1,      # events
            0,      # mute
            15350,  # DELTA1
            666,    # DELTA2
            600,    # DELTA3
            50     # DELTA4
        ),

        (
            0b01000000,   # pwm_pin
            0.25, # pwm duty cycle
            10000., # pwm frequency (hz)
            0b10000000, # output mask
            1,      # events
            0,      # mute
            15350,  # DELTA1
            666,    # DELTA2
            600,    # DELTA3
            50     # DELTA4
        )
    ]

    data_fmt = "<LffLBBLLLL"

    print("\nDisabling schedule.")
    device.send(WriteU8HarpMessage(AppRegs.SetTasksState, 0).frame)
    print("\nClearing all tasks.")
    device.send(WriteU8HarpMessage(AppRegs.RemoveAllLaserTasks, 1).frame)

    check_configured_tasks(device)

    print("\n########################################")
    print("Configuring device with 4 FIP tasks.")
    device.send(WriteU8ArrayMessage(AppRegs.AddLaserTask, data_fmt, settings[0]).frame)
    device.send(WriteU8ArrayMessage(AppRegs.AddLaserTask, data_fmt, settings[1]).frame)
    device.send(WriteU8ArrayMessage(AppRegs.AddLaserTask, data_fmt, settings[2]).frame)
    device.send(WriteU8ArrayMessage(AppRegs.AddLaserTask, data_fmt, settings[3]).frame)
    check_configured_tasks(device)

    print("\n########################################")
    print("Reconfiguring task 1.")
    device.send(WriteU8ArrayMessage(AppRegs.ReconfigureLaserTask1, data_fmt, settings[3]).frame)
    check_configured_tasks(device)

    print("\n########################################")
    print("Removing task 1.")
    device.send(WriteU8HarpMessage(AppRegs.RemoveLaserTask, 1).frame)
    check_configured_tasks(device)

    print("\n########################################")
    print("Reconfiguring task 3.")
    # Should return an error since task 3 is not configured anymore
    print(device.send(WriteU8ArrayMessage(AppRegs.ReconfigureLaserTask3, data_fmt, settings[0]).frame))
    check_configured_tasks(device)


# Function to check configured tasks
def check_configured_tasks(device):

    print("Checking configured tasks...")
    print("Task count: ", device.send(ReadU8HarpMessage(AppRegs.LaserTaskcount).frame).payload_as_int())
    print("----------------------")

    task0 = device.send(ReadU8HarpMessage(AppRegs.ReconfigureLaserTask0).frame)
    print("TASK 0 payload: ", task0.payload)
    print("----------------------")

    task1 = device.send(ReadU8HarpMessage(AppRegs.ReconfigureLaserTask1).frame)
    print("TASK 1 payload: ", task1.payload)
    print("----------------------")

    task2 = device.send(ReadU8HarpMessage(AppRegs.ReconfigureLaserTask2).frame)
    print("TASK 2 payload: ", task2.payload)
    print("----------------------")

    task3 = device.send(ReadU8HarpMessage(AppRegs.ReconfigureLaserTask3).frame)
    print("TASK 3 payload: ", task3.payload)
    print("----------------------")


if __name__ == "__main__":
    try:
        device = find_device()
        device.info()

        configure_tasks(device)

        sys.exit(0)

    except Exception as e:
        print("An error occurred:", e)

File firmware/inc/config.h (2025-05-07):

#ifndef CONFIG_H
#define CONFIG_H


/*
inline constexpr uint16_t HARP_DEVICE_ID = 0x057B; // FIXME: should be distinct from old cuttlefish.
inline constexpr uint16_t WHO_AM_I = HARP_DEVICE_ID;
inline constexpr uint8_t HW_VERSION_MAJOR = 0;
inline constexpr uint8_t HW_VERSION_MINOR = 0;
inline constexpr uint8_t ASSEMBLY_VERSION = 0;
inline constexpr uint8_t HARP_VERSION_MAJOR = 0;
inline constexpr uint8_t HARP_VERSION_MINOR = 0;
inline constexpr uint8_t FW_VERSION_MAJOR = 0;
inline constexpr uint8_t FW_VERSION_MINOR = 0;
inline constexpr uint16_t SERIAL_NUMBER = 0;
*/

#define FIP_HARP_DEVICE_ID (0x057F)
#define FIP_WHO_AM_I (FIP_HARP_DEVICE_ID)

#define DEBUG_UART (uart0)
#define DEBUG_UART_TX_PIN (0) // for printf-style debugging.

#define SYNC_UART (uart1)
#define HARP_SYNC_RX_PIN (5)
#define LED0 (24)
#define LED1 (25)

#define PORT_BASE (8)
#define PORT_DIR_BASE (16)


#define MAX_TASK_COUNT (8)

inline constexpr uint8_t MAX_QUEUE_SIZE = 32;

#endif // CONFIG_H

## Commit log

2023-10-04 initial commit; draft schematic
    [harp_core_rp2040_w_isolated_usb.kicad_sch, octal_ttl_io.kicad_sch, power_supplies.kicad_sch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]
2023-10-04 draft mcu bypass with bus switches
    [harp_core_rp2040_w_isolated_usb.kicad_sch, octal_ttl_io.kicad_sch, power_supplies.kicad_sch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]
2023-10-05 update schematic with bus switches
    [harp_core_rp2040_w_isolated_usb.kicad_sch, ttl_io.kicad_sch]
2023-10-28 update passthrough level translator
    [harp_core_rp2040_w_isolated_usb.kicad_sch, octal_ttl_io.kicad_sch, power_supplies.kicad_sch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]
2023-12-22 update layout
    [octal_ttl_io.kicad_sch, ttl_io.kicad_pcb, ttl_io.kicad_sch]
2024-01-02 update power supply schematic/board
    [octal_ttl_io.kicad_sch, power_supplies.kicad_sch, ttl_io.kicad_pcb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]
2024-01-02 annotate bus logic on schematic
    [harp_core_rp2040_w_isolated_usb.kicad_sch, ttl_io.kicad_pcb, ttl_io.kicad_sch]
2024-01-03 update pcb
    [bus_selection.kicad_sch, ttl_io.kicad_pcb, ttl_io.kicad_sch]
2024-01-05 draft pcb v0.1.0
    [harp_core_rp2040_w_isolated_usb.kicad_sch, power_supplies.kicad_sch, ttl_io.kicad_pcb]
2024-01-12 update pcb and bom
    [bus_selection.kicad_sch, octal_ttl_io.kicad_sch, power_supplies.kicad_sch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]
2024-01-12 add hw/fw licenses
    [power_supplies.kicad_sch, ttl_io.kicad_pcb]
2024-01-18 draft scheduler
    [ttl_io.kicad_pcb, ttl_io.kicad_sch]
2024-01-22 crude pwm blink task works
2024-01-27 add pin mask and cpu profiling
2024-01-27 pwm mask demo
2024-02-13 add enclosure cad model
    [cuttlefish_enclosure.SLDPRT]
2024-02-13 update enclosure
    [cuttlefish_enclosure.SLDPRT]
2024-02-15 update case cad with laser cut offsets
    [cuttlefish_enclosure.SLDPRT]
2024-02-16 update enclosure wall clearances
    [cuttlefish_enclosure.SLDPRT]
2024-03-25 Add device.yml
2024-03-25 Add helper method to configure PWM
2024-08-08 enable external pin to trigger schedule
2024-08-09 implement finite pulses
    [ttl_io.kicad_pcb]
2024-08-12 get pwm task and ios working
    [bus_selection.kicad_sch, power_supplies.kicad_sch, ttl_io.kicad_pcb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]
2024-11-10 Favor harp-tech as source of device schema
2025-03-18 update readme; submodule pwm lib
2025-03-21 draft working pwm task
2025-04-04 draft minimal laser-fip-task-centric approach
2025-04-11 bugfix pwm re-init
2025-04-17 configure cuttelfish bus switches for sw control.
2025-04-21 translate PCB output to GPIO output
2025-04-21 make device disable upon entering STANDBY op mode.
2025-04-22 fix rising edge output gpio offset
    [cuttlefish_fip_app.cpp, send_fip_waveform_and_get_events.py]
2025-04-30 fix laser base address calculation
2025-04-30 fix task removal logic and update task settings registers
    [cuttlefish_fip_app.cpp]
2025-04-30 fix PWM pin and output mask offsets in laser task reconfiguration
    [cuttlefish_fip_app.cpp]
2025-04-30 update FIP device ID and set whoAmI to 1407
2025-04-30 make laser task pin one-hot encoded
2025-05-07 fix: convert rising edge tstamp to harp clock domain
    [cuttlefish_fip_app.cpp]
2025-06-03 refactor: replace EnableTaskSchedule with SetTasksState and add abort functionality
    [cuttlefish_fip_app.cpp, fip_schedule.cpp, main.cpp]
2025-06-03 replace EnableTaskSchedule with SetTasksState in pyharp tests
    [configure_and_check_tasks.py, send_fip_waveform.py, send_fip_waveform_and_disconnect.py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]
2025-06-03 Regenerate device
2025-06-28 Update test script to print nominal delta-T and error values
    [send_fip_waveform_and_measure_time_delta.py]
